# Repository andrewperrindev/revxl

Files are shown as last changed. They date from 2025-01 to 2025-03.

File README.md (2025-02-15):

# The RevXL Keyboard

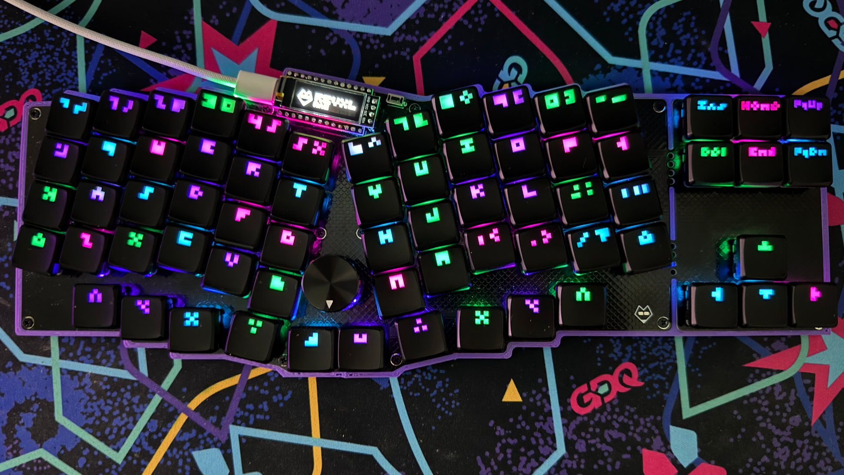
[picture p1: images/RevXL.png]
The RevXL


The RevXL is a maximalist Reviung-inspired ergonomic keyboard with per-key RGB LEDs, an OLED display, a rotary encoder, and a breakaway arrow cluster. It’s powered by a wired RP2040 microcontroller with QMK and Vial handling things on the firmware side. At its core, the RevXL is designed to be an on ramp to the ergonomic mechanical keyboard space. It shows off the scene’s most catchy bells and whistles while still providing a few creature comforts of more traditional layouts.

## Sponsored By PCBWay

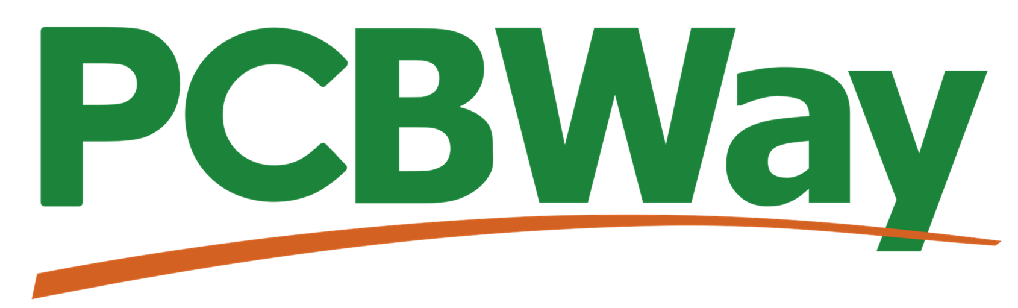
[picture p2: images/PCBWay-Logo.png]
PCBWay Logo


This project is sponsored by [PCBWay](https://www.pcbway.com). They're the internet's premier PCB fabricator and are a one-stop-shop for all your prototyping needs. They offer PCB fabrication services, 3D printing with a variety of materials, and even PCBA assembly services for those of you who prefer not to solder their own projects. If it can be represented as a design file, you can probably upload it to [PCBWay](https://www.pcbway.com) and receive it a few days later in the mail.

PCBWay did a great job manufacturing the RevXL PCB. The order shipped quickly, and all of the PCBs arrived safe and sound inside of a well packed box and vacuum sealed bubbled wrap. My thanks to [PCBWay](https://www.pcbway.com) for helping to make this keyboard a reality.

## Ergogen Layout

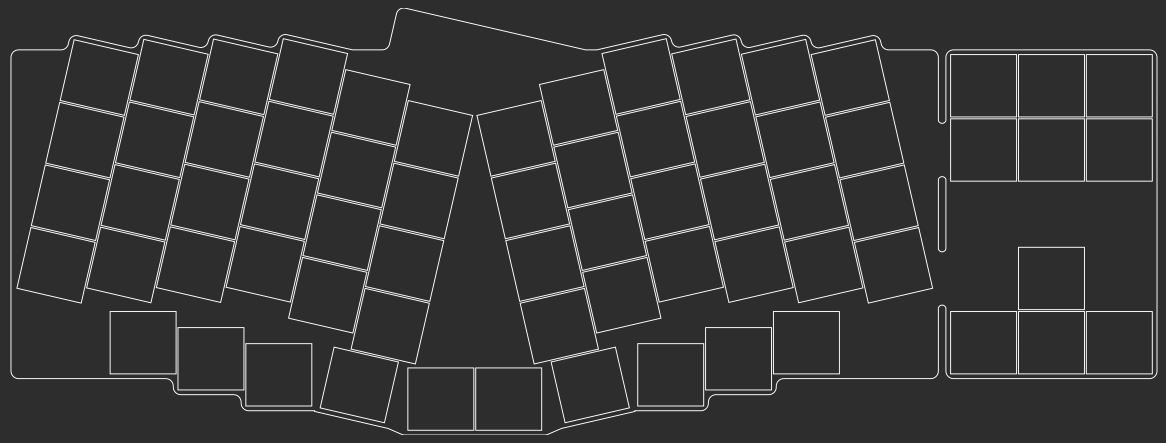
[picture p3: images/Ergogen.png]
Ergogen Preview


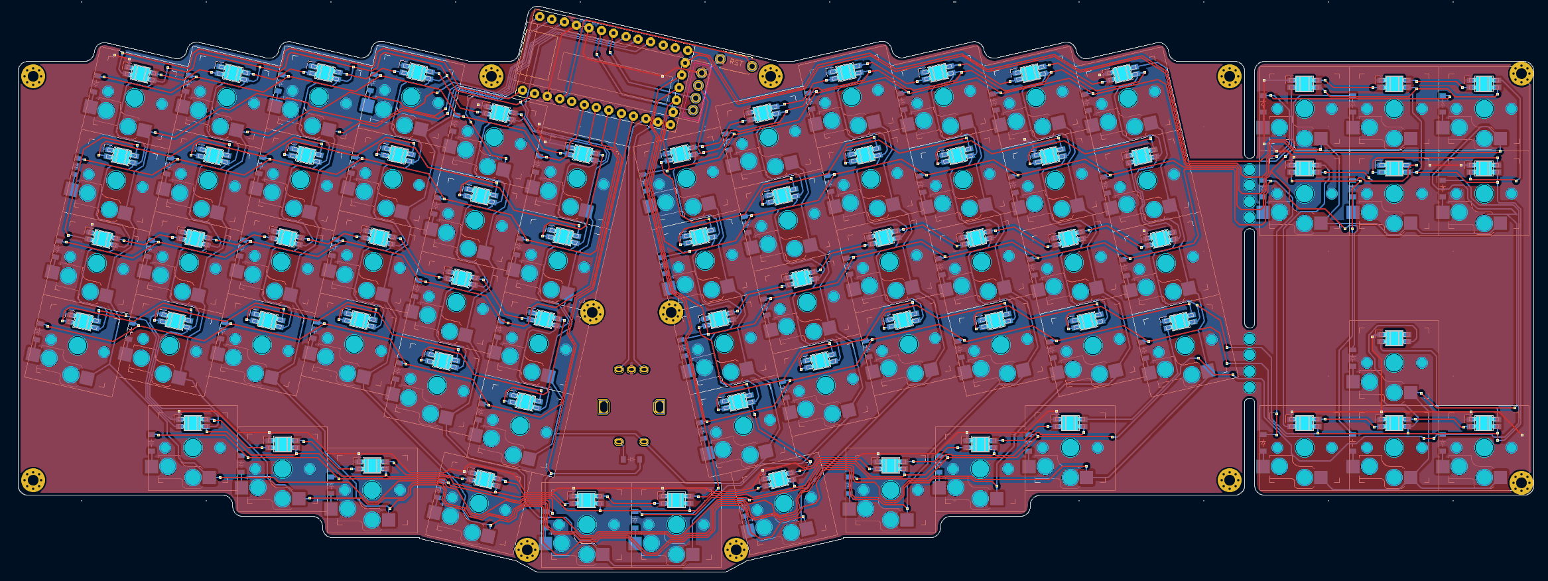
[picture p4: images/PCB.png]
KiCAD Preview


The RevXL was designed with the Ergogen keyboard layout generator. The techniques used here are similar to those I detailed in my [Ergogen tutorial series](https://flatfootfox.com/ergogen-introduction/). The largest new additions were the considerations needed for the per-key RGB LEDs and the breakaway arrow cluster.

## Custom Keycaps

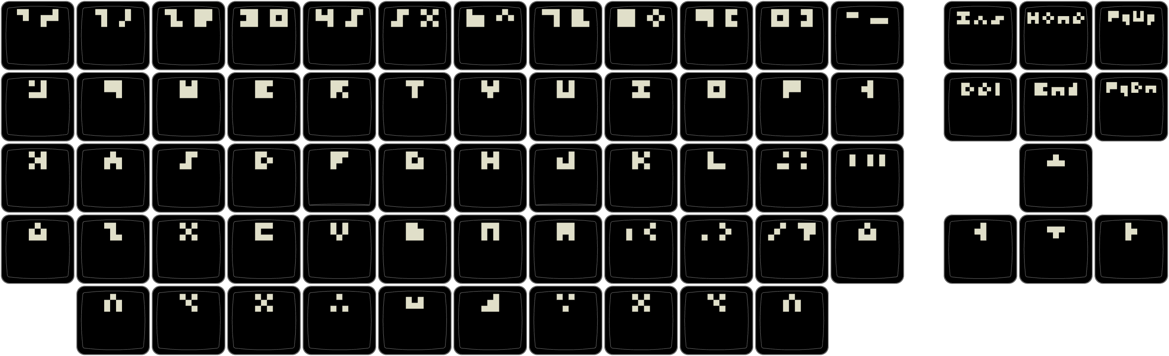
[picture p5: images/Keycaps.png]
Keycap Preview


I needed to order a few additional keycaps from [FK Caps](https://fkcaps.com/?a=FlatFootFox) to fill out the arrow key cluster. I decided to use that was an excuse to create a whole custom keycap layout. It's based around a minimalist 3x3 pixel font. You can *just* make out the key glyphs if you squint.

## Build of Materials

| Part | Amount | Price | Link |
| --- | --- | --- | --- |
| Revxl PCB via PCBWay | 1 | $60.00 USD Shipped | https://github.com/ImStuBTW/revxl |
| RP2040 "Pro Micro" | 1 | $3.00 USD | https://www.aliexpress.us/item/3256806423363289.html |
| Choc Switches | 68 | $40.00 USD | https://www.aliexpress.us/item/3256805697157410.html |
| 1N4148 T4 Diodes | 68 | $2.00 USD | https://www.aliexpress.us/item/2255800498728983.html |
| SK6812 MINI-E RGB LEDs | 68 | $2.00 USD | https://www.aliexpress.us/item/2255800498728983.html |
| EC11 Rotary Encoder | 1 | $2.50 USD | https://www.aliexpress.us/item/2255800160725313.html |
| EC11 20x15mm Knob | 1 | $3.00 USD | https://www.aliexpress.us/item/2251832562966356.html |
| MBK Glow Keycaps | 1 | $55.00 USD | https://lowprokb.ca/collections/keycaps/products/mbk-glow-r2-keycap-sets |
| 6mm x 3mm x 4.3mm Pushbutton | 1 | $2.00 USD | https://www.aliexpress.us/item/3256801663262003.html |
| Machine Pins | 35 | $6.00 USD | https://www.aliexpress.us/item/3256801663262003.html |
| Machine Pin Headers | 39 | $4.00 USD | https://www.aliexpress.us/item/3256801663262003.html |
| 4mm M2 Screws | 8 | $1.00 USD | https://www.aliexpress.us/item/2255801062616407.html |
| 2mm M2 Screw Inserts | 8 | $1.50 USD | https://www.aliexpress.us/item/3256804349544912.html |
| Bumpons | 1 Pack | $1.00 USD | https://www.aliexpress.us/item/3256804119199524.html |

# References and Footprints

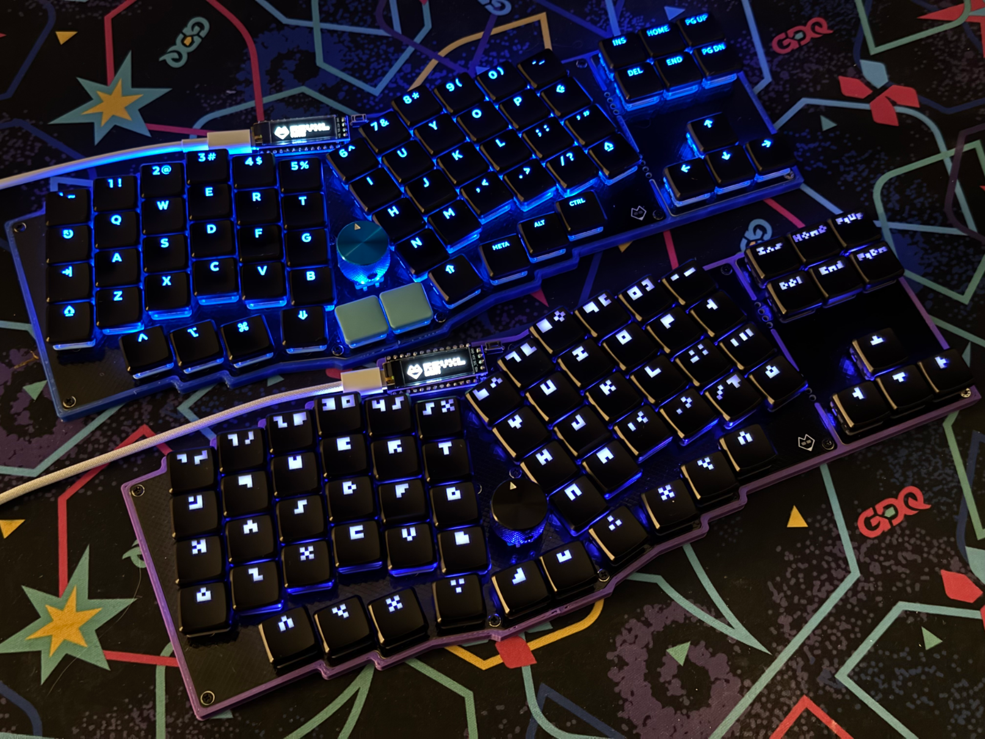
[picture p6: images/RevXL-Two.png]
Two of them


The [Reviung](https://github.com/gtips/reviung) layout concept was based after gtips' original design. The split thumb design was inspired heavily by Pete Johanson's [revxlp](https://gitlab.com/lpgalaxy/revxlp). For a similar keyboard design available in kit form without the arrow keys, please check out 42Keeb's excellent [Rev57LP](https://42keebs.eu/shop/kits/pro-micro-based/rev57lp-50-low-profile-hotswap-ergo-kit/). They've added RGB LED support in the time it took me to create this keyboard.

The breakaway arrow cluster concept was inspired by the Afternoon Labs [Breeze](https://www.afternoonlabs.com/breeze/) keyboard.

Thanks to Moonbase for the [pixel font breakdown](https://moonbench.xyz/projects/tiny-pixel-art-fonts/)! 

Cheers to Ceoloide's [Ergogen-Footprints](https://github.com/ceoloide/ergogen-footprints) repo. There's more elegant ways of including it as a local git submodule. I may have just chucked their diode, display, LED, reset switch, rotary encoder, and Choc switch footprints into my `/footprints` folder.

The RP2040 footprint was based off rroel's [KiCAD footprint](https://github.com/rroels/kicad_pro_micro_rp2040).

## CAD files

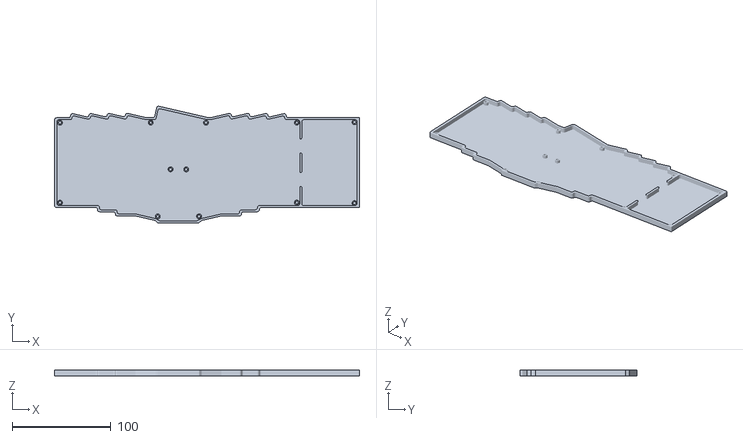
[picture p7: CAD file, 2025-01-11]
output/cases/case.stl
309.0 x 118.1 x 5.60

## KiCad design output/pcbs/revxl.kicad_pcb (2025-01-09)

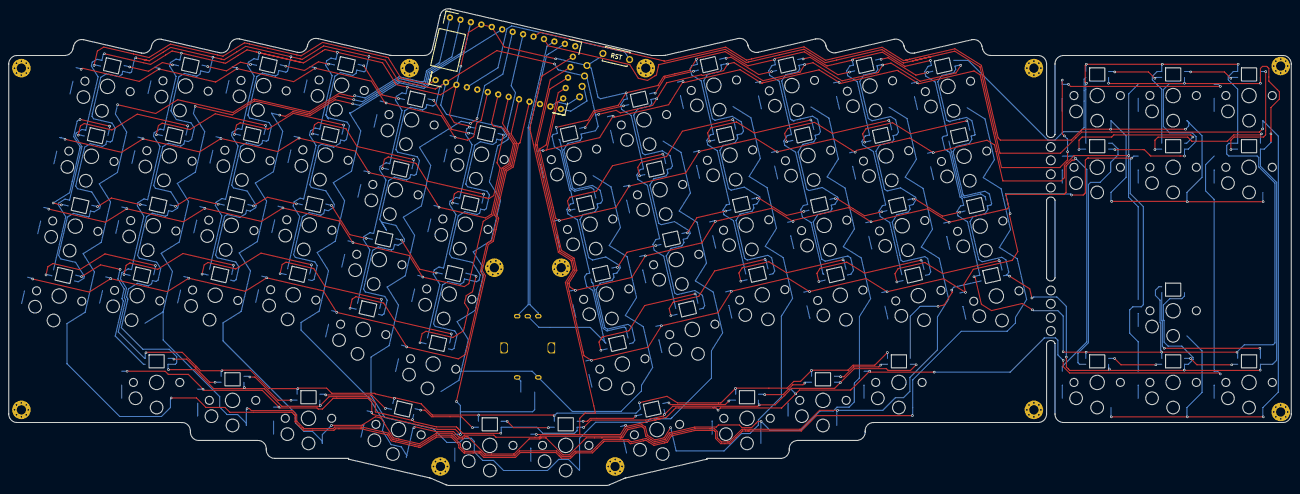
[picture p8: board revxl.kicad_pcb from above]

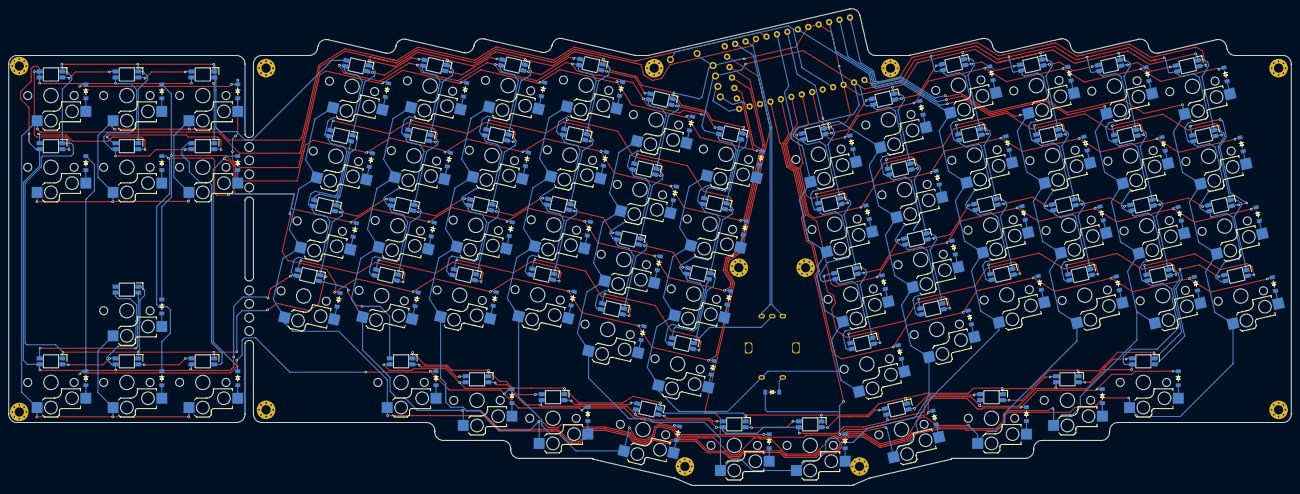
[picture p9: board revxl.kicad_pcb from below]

Board: 2 copper layers, 304.0 x 113.0 mm, 228 parts (205 on the bottom side), 156 nets.

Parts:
D1, D2, D3, D4, D5, D6, D7, D8, D9, D10, D11, D12, D13, D14, D15, D16, D17, D18, D19, D20, D21, D22, D23, D24, D25, D26, D27, D28, D29, D30, D31, D32, D33, D34, D35, D36, D37, D38, D39, D40, D41, D42, D43, D44, D45, D46, D47, D48, D49, D50, D51, D52, D53, D54, D55, D56, D57, D58, D59, D60, D61, D62, D63, D64, D65, D66, D67, D68, D69: diode_tht_sod123
DISP1: display_ssd1306
LED1, LED2, LED3, LED4, LED5, LED6, LED7, LED8, LED9, LED10, LED11, LED12, LED13, LED14, LED15, LED16, LED17, LED18, LED19, LED20, LED21, LED22, LED23, LED24, LED25, LED26, LED27, LED28, LED29, LED30, LED31, LED32, LED33, LED34, LED35, LED36, LED37, LED38, LED39, LED40, LED41, LED42, LED43, LED44, LED45, LED46, LED47, LED48, LED49, LED50, LED51, LED52, LED53, LED54, LED55, LED56, LED57, LED58, LED59, LED60, LED61, LED62, LED63, LED64, LED65, LED66, LED67, LED68: led_SK6812mini-e (per-keysingle-side)
RE1: rotary_encoder_ec11_ec12
RST1: reset_switch_tht_top
S1, S2, S3, S4, S5, S6, S7, S8, S9, S10, S11, S12, S13, S14, S15, S16, S17, S18, S19, S20, S21, S22, S23, S24, S25, S26, S27, S28, S29, S30, S31, S32, S33, S34, S35, S36, S37, S38, S39, S40, S41, S42, S43, S44, S45, S46, S47, S48, S49, S50, S51, S52, S53, S54, S55, S56, S57, S58, S59, S60, S61, S62, S63, S64, S65, S66, S67, S68: switch_choc_v1_v2
_1, _2, _3, _4, _5, _6, _7, _8, _9, _10, _11, _12, _13, _14, _15, _16, _17, _18, _19, _20: MountingHole_2.2mm_M2_Pad_Via

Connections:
GND: DISP1.4, LED1.3, LED2.3, LED3.3, LED4.3, LED5.3, LED6.3, LED7.3, LED8.3, LED9.3, LED10.3, LED11.3, LED12.3, LED13.3, LED14.3, LED15.3, LED16.3, LED17.3, LED18.3, LED19.3, LED20.3, LED21.3, LED22.3, LED23.3, LED24.3, LED25.3, LED26.3, LED27.3, LED28.3, LED29.3, LED30.3, LED31.3, LED32.3, LED33.3, LED34.3, LED35.3, LED36.3, LED37.3, LED38.3, LED39.3, LED40.3, LED41.3, LED42.3, LED43.3, LED44.3, LED45.3, LED46.3, LED47.3, LED48.3, LED49.3, LED50.3, LED51.3, LED52.3, LED53.3, LED54.3, LED55.3, LED56.3, LED57.3, LED58.3, LED59.3, LED60.3, LED61.3, LED62.3, LED63.3, LED64.3, LED65.3, LED66.3, LED67.3, LED68.3, RE1.B, RST1.2
LED1: LED4.2, LED8.4
LED2: LED8.2, LED12.4
LED3: LED12.2, LED16.4
LED4: LED16.2, LED20.4
LED5: LED20.2, LED24.4
LED6: LED23.4, LED24.2
LED7: LED19.4, LED23.2
LED8: LED15.4, LED19.2
LED9: LED11.4, LED15.2
LED10: LED7.4, LED11.2
LED11: LED3.4, LED7.2
LED12: LED2.4, LED3.2
LED13: LED2.2, LED6.4
LED14: LED6.2, LED10.4
LED15: LED10.2, LED14.4
LED16: LED14.2, LED18.4
LED17: LED18.2, LED22.4
LED18: LED21.4, LED22.2
LED19: LED17.4, LED21.2
LED20: LED13.4, LED17.2
LED21: LED9.4, LED13.2
LED22: LED5.4, LED9.2
LED23: LED1.4, LED5.2
LED24: LED1.2, LED49.4
LED25: LED49.2, LED50.4
LED26: LED50.2, LED51.4
LED27: LED51.2, LED55.4
LED28: LED55.2, LED57.4
LED29: LED57.2, LED58.4
LED30: LED56.4, LED58.2
LED31: LED54.4, LED56.2
LED32: LED53.4, LED54.2
LED33: LED52.4, LED53.2
LED34: LED25.4, LED52.2
LED35: LED25.2, LED29.4
LED36: LED29.2, LED33.4
LED37: LED33.2, LED37.4
LED38: LED37.2, LED41.4
LED39: LED41.2, LED45.4
LED40: LED45.2, LED46.4
LED41: LED42.4, LED46.2
LED42: LED38.4, LED42.2
LED43: LED34.4, LED38.2
LED44: LED30.4, LED34.2
LED45: LED26.4, LED30.2
LED46: LED26.2, LED27.4
LED47: LED27.2, LED31.4
LED48: LED31.2, LED35.4
LED49: LED35.2, LED39.4
LED50: LED39.2, LED43.4
LED51: LED43.2, LED47.4
LED52: LED47.2, LED48.4
LED53: LED44.4, LED48.2
LED54: LED40.4, LED44.2
LED55: LED36.4, LED40.2
LED56: LED32.4, LED36.2
LED57: LED28.4, LED32.2
LED58: LED28.2, LED61.4
LED59: LED61.2, LED65.4
LED60: LED65.2, LED68.4
LED61: LED67.4, LED68.2
LED62: LED64.4, LED67.2
LED63: LED60.4, LED64.2
LED64: LED59.4, LED60.2
LED65: LED59.2, LED62.4
LED66: LED62.2, LED66.4
LED67: LED63.4, LED66.2
VCC: DISP1.3, LED1.1, LED2.1, LED3.1, LED4.1, LED5.1, LED6.1, LED7.1, LED8.1, LED9.1, LED10.1, LED11.1, LED12.1, LED13.1, LED14.1, LED15.1, LED16.1, LED17.1, LED18.1, LED19.1, LED20.1, LED21.1, LED22.1, LED23.1, LED24.1, LED25.1, LED26.1, LED27.1, LED28.1, LED29.1, LED30.1, LED31.1, LED32.1, LED33.1, LED34.1, LED35.1, LED36.1, LED37.1, LED38.1, LED39.1, LED40.1, LED41.1, LED42.1, LED43.1, LED44.1, LED45.1, LED46.1, LED47.1, LED48.1, LED49.1, LED50.1, LED51.1, LED52.1, LED53.1, LED54.1, LED55.1, LED56.1, LED57.1, LED58.1, LED59.1, LED60.1, LED61.1, LED62.1, LED63.1, LED64.1, LED65.1, LED66.1, LED67.1, LED68.1
alt_modrow: D50.2, S50.2
center_del: D64.2, S64.2
center_down: D62.2, S62.2
center_ins: D65.2, S65.2
center_up: D63.2, S63.2
col0: S1.1, S2.1, S3.1, S4.1, S25.1, S26.1, S27.1, S28.1, S49.1, S52.1
col1: S5.1, S6.1, S7.1, S8.1, S29.1, S30.1, S31.1, S32.1, S50.1, S53.1
col2: S9.1, S10.1, S11.1, S12.1, S33.1, S34.1, S35.1, S36.1, S51.1, S54.1
col3: S13.1, S14.1, S15.1, S16.1, S37.1, S38.1, S39.1, S40.1, S55.1, S56.1
col4: S17.1, S18.1, S19.1, S20.1, S41.1, S42.1, S43.1, S44.1, S57.1, S58.1
col5: RE1.S1, S21.1, S22.1, S23.1, S24.1, S45.1, S46.1, S47.1, S48.1
col6: S60.1, S61.1, S64.1, S65.1, S67.1
col7: S59.1, S62.1, S63.1, S66.1, S68.1
ctrl_modrow: D49.2, S49.2
endiode: D69.2, RE1.S2
index_bottom: D17.2, S17.2
index_home: D18.2, S18.2
index_num: D20.2, S20.2
index_top: D19.2, S19.2
inner_bottom: D21.2, S21.2
inner_home: D22.2, S22.2
inner_num: D24.2, S24.2
inner_top: D23.2, S23.2
layercol_layerrow: D55.2, S55.2
left_del: D60.2, S60.2
left_down: D59.2, S59.2
left_ins: D61.2, S61.2
middle_bottom: D13.2, S13.2
middle_home: D14.2, S14.2
middle_num: D16.2, S16.2
middle_top: D15.2, S15.2
mirror_alt_modrow: D53.2, S53.2
mirror_ctrl_modrow: D52.2, S52.2
mirror_index_bottom: D41.2, S41.2
mirror_index_home: D42.2, S42.2
mirror_index_num: D44.2, S44.2
mirror_index_top: D43.2, S43.2
mirror_inner_bottom: D45.2, S45.2
mirror_inner_home: D46.2, S46.2
mirror_inner_num: D48.2, S48.2
mirror_inner_top: D47.2, S47.2
mirror_layercol_layerrow: D56.2, S56.2
mirror_middle_bottom: D37.2, S37.2
mirror_middle_home: D38.2, S38.2
mirror_middle_num: D40.2, S40.2
mirror_middle_top: D39.2, S39.2
mirror_outer_bottom: D25.2, S25.2
mirror_outer_home: D26.2, S26.2
mirror_outer_num: D28.2, S28.2
mirror_outer_top: D27.2, S27.2
mirror_pinky_bottom: D29.2, S29.2
mirror_pinky_home: D30.2, S30.2
mirror_pinky_num: D32.2, S32.2
mirror_pinky_top: D31.2, S31.2
mirror_ring_bottom: D33.2, S33.2
mirror_ring_home: D34.2, S34.2
mirror_ring_num: D36.2, S36.2
mirror_ring_top: D35.2, S35.2
mirror_spacecol_spacerow: D58.2, S58.2
mirror_super_modrow: D54.2, S54.2
outer_bottom: D1.2, S1.2
outer_home: D2.2, S2.2
outer_num: D4.2, S4.2
outer_top: D3.2, S3.2
pinky_bottom: D5.2, S5.2
pinky_home: D6.2, S6.2
pinky_num: D8.2, S8.2
pinky_top: D7.2, S7.2
right_del: D67.2, S67.2
right_down: D66.2, S66.2
right_ins: D68.2, S68.2
ring_bottom: D9.2, S9.2
ring_home: D10.2, S10.2
ring_num: D12.2, S12.2
ring_top: D11.2, S11.2
row0: D4.1, D8.1, D12.1, D16.1, D20.1, D24.1
row1: D3.1, D7.1, D11.1, D15.1, D19.1, D23.1
row2: D2.1, D6.1, D10.1, D14.1, D18.1, D22.1
row3: D1.1, D5.1, D9.1, D13.1, D17.1, D21.1
row4: D49.1, D50.1, D51.1, D55.1, D57.1, D69.1
row5: D28.1, D32.1, D36.1, D40.1, D44.1, D48.1, D61.1, D68.1
row6: D27.1, D31.1, D35.1, D39.1, D43.1, D47.1, D63.1, D65.1
row7: D26.1, D30.1, D34.1, D38.1, D42.1, D46.1, D59.1, D60.1
row8: D25.1, D29.1, D33.1, D37.1, D41.1, D45.1, D62.1, D64.1
row9: D52.1, D53.1, D54.1, D56.1, D58.1, D66.1, D67.1
spacecol_spacerow: D57.2, S57.2
super_modrow: D51.2, S51.2

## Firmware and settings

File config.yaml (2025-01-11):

meta:
  engine: 4.1.0
units:
  $default_width: cx
  $default_height: cy
  angle: -13
  mirror_gap: 3cx-1.5
  pad: 2
  hpad: pad/2
  cpad: 6
  chpad: cpad/2
  # M2 Screws
  screwSize: 1.5
  standoffSize: 2.5
points:
  zones:
    matrix:
      anchor:
        shift: [100, -100]
      rotate: angle
      mirror: &mirror
        ref: matrix_inner_bottom
        shift: [0, -cy]
        distance: mirror_gap
      key:
        spread: cx
        padding: cy
      columns:
        outer:
          key:
            column_net: col0
          rows:
            bottom:
              key:
                led_prev: LED23
                led_next: LED24
              mirror.key:
                led_prev: LED34
                led_next: LED35
            home:
              key:
                led_prev: LED12
                led_next: LED13
              mirror.key:
                led_prev: LED45
                led_next: LED46
            top:
              key:
                led_prev: LED11
                led_next: LED12
              mirror.key:
                led_prev: LED46
                led_next: LED47
            num:
              key:
                led_prev: LED
                led_next: LED1
              mirror.key:
                led_prev: LED57
                led_next: LED58
        pinky:
          key:
            stagger: 0.25cy
            column_net: col1
          rows:
            bottom:
              key:
                led_prev: LED22
                led_next: LED23
              mirror.key:
                led_prev: LED35
                led_next: LED36
            home:
              key:
                led_prev: LED13
                led_next: LED14
              mirror.key:
                led_prev: LED44
                led_next: LED45
            top:
              key:
                led_prev: LED10
                led_next: LED11
              mirror.key:
                led_prev: LED47
                led_next: LED48
            num:
              key:
                led_prev: LED1
                led_next: LED2
              mirror.key:
                led_prev: LED56
                led_next: LED57
        ring:
          key:
            stagger: 0.25cy
            column_net: col2
          rows:
            bottom:
              key:
                led_prev: LED21
                led_next: LED22
              mirror.key:
                led_prev: LED36
                led_next: LED37
            home:
              key:
                led_prev: LED14
                led_next: LED15
              mirror.key:
                led_prev: LED43
                led_next: LED44
            top:
              key:
                led_prev: LED9
                led_next: LED10
              mirror.key:
                led_prev: LED48
                led_next: LED49
            num:
              key:
                led_prev: LED2
                led_next: LED3
              mirror.key:
                led_prev: LED55
                led_next: LED56
        middle:
          key:
            stagger: 0.25cy
            column_net: col3
          rows:
            bottom:
              key:
                led_prev: LED20
                led_next: LED21
              mirror.key:
                led_prev: LED37
                led_next: LED38
            home:
              key:
                led_prev: LED15
                led_next: LED16
              mirror.key:
                led_prev: LED42
                led_next: LED43
            top:
              key:
                led_prev: LED8
                led_next: LED9
              mirror.key:
                led_prev: LED49
                led_next: LED50
            num:
              key:
                led_prev: LED3
                led_next: LED4
              mirror.key:
                led_prev: LED54
                led_next: LED55
        index:
          key:
            stagger: -0.25cy
            column_net: col4
          rows:
            bottom:
              key:
                led_prev: LED19
                led_next: LED20
              mirror.key:
                led_prev: LED38
                led_next: LED39
            home:
              key:
                led_prev: LED16
                led_next: LED17
              mirror.key:
                led_prev: LED41
                led_next: LED42
            top:
              key:
                led_prev: LED7
                led_next: LED8
              mirror.key:
                led_prev: LED50
                led_next: LED51
            num:
              key:
                led_prev: LED4
                led_next: LED5
              mirror.key:
                led_prev: LED53
                led_next: LED54
        inner:
          key:
            stagger: -0.25cy
            column_net: col5
          rows:
            bottom:
              key:
                led_prev: LED18
                led_next: LED19
              mirror.key:
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

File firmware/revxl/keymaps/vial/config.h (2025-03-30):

#pragma once

#define VIAL_KEYBOARD_UID {0xBF, 0xAD, 0xAA, 0xA1, 0x33, 0xD1, 0x3F, 0x17}

#define I2C_DRIVER I2CD1
#define I2C1_SDA_PIN GP2
#define I2C1_SCL_PIN GP3

#define OLED_TIMEOUT 120000
#define OLED_BRIGHTNESS 120

#define RGB_MATRIX_SLEEP
#define RGB_MATRIX_MAXIMUM_BRIGHTNESS 100
#define RGB_MATRIX_SOLID_REACTIVE_GRADIENT_MODE

#define TAPPING_TOGGLE 3

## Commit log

2025-01-08 Init Commit
    [revxl.kicad_pcb]
2025-01-09 Added Ergogen Screenshot
    [revxl.kicad_pcb]
2025-01-11 Rewired. Added case.
    [case.stl]
